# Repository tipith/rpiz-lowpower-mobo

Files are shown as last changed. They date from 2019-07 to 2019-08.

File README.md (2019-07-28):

# Motherboard

Purpose of this PCB is have a low-power way of sending SMS messages once an external trigger is detected. For example, it can be used as a an detector for door open events.

Features
- 18650 battery holder
- Attiny1604 power manager
- External trigger connector
- Nokia phone connector (FBUS + battery size indicator + battery temp)
- 2-way communication between PM and RPi

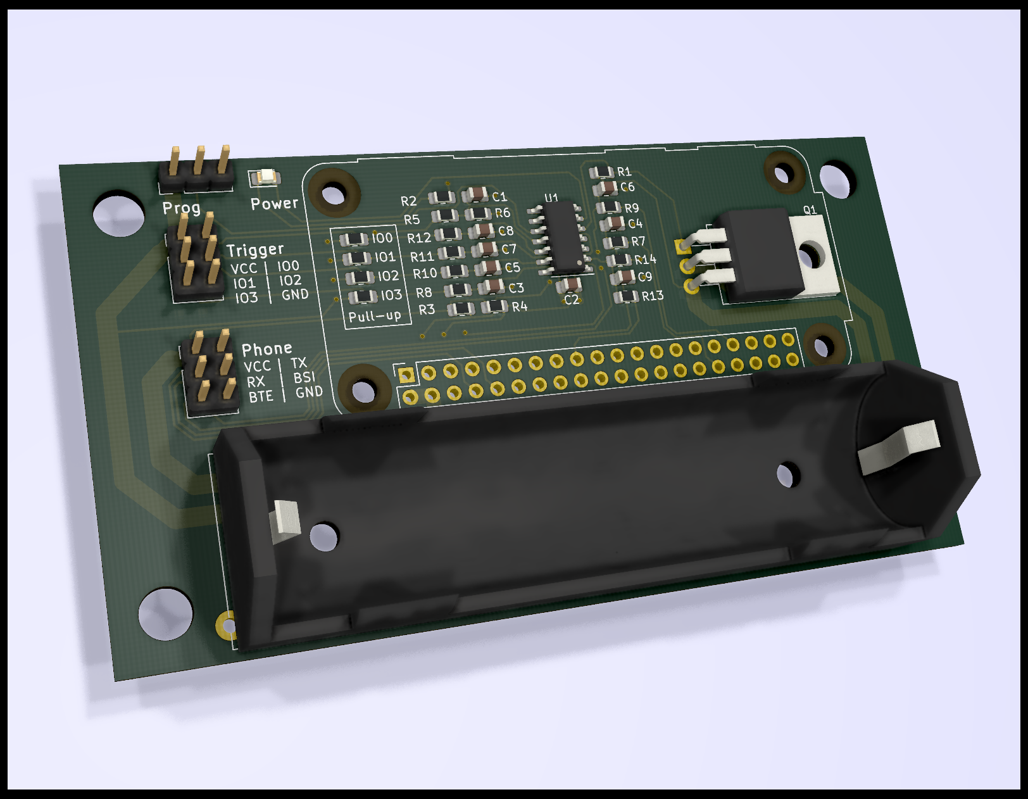
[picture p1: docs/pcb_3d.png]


# Power manager (attiny1604)

tbd

# SMS sender (RPi Zero)

## Instructions

- /boot
   - add file: sshe
   - add file: wpa_supplicant.conf
   - add file: trapsms.ini
- /boot/config.txt
   - add "dtoverlay rpi3-disable-bt"
   - uncomment and modify "dtparam=i2c_arm=on,i2c_arm_baudrate=50000"
-  /boot/cmdline.txt
   - remove "console=serial0,115200 console=tty1"
- shell commands
   - sudo systemctl disable hciuart
   - sudo apt update && sudo apt upgrade
   - sudo apt install git gammu python3-gammu
- install pigpio
  - sudo apt-get install pigpio
  - wget https://raw.githubusercontent.com/joan2937/pigpio/master/util/pigpiod.service
  - sudo cp pigpiod.service /etc/systemd/system
  - sudo systemctl enable pigpiod.service
  - sudo systemctl start pigpiod.service
- run
   - python3 rpi_smssender/sms_sender.py

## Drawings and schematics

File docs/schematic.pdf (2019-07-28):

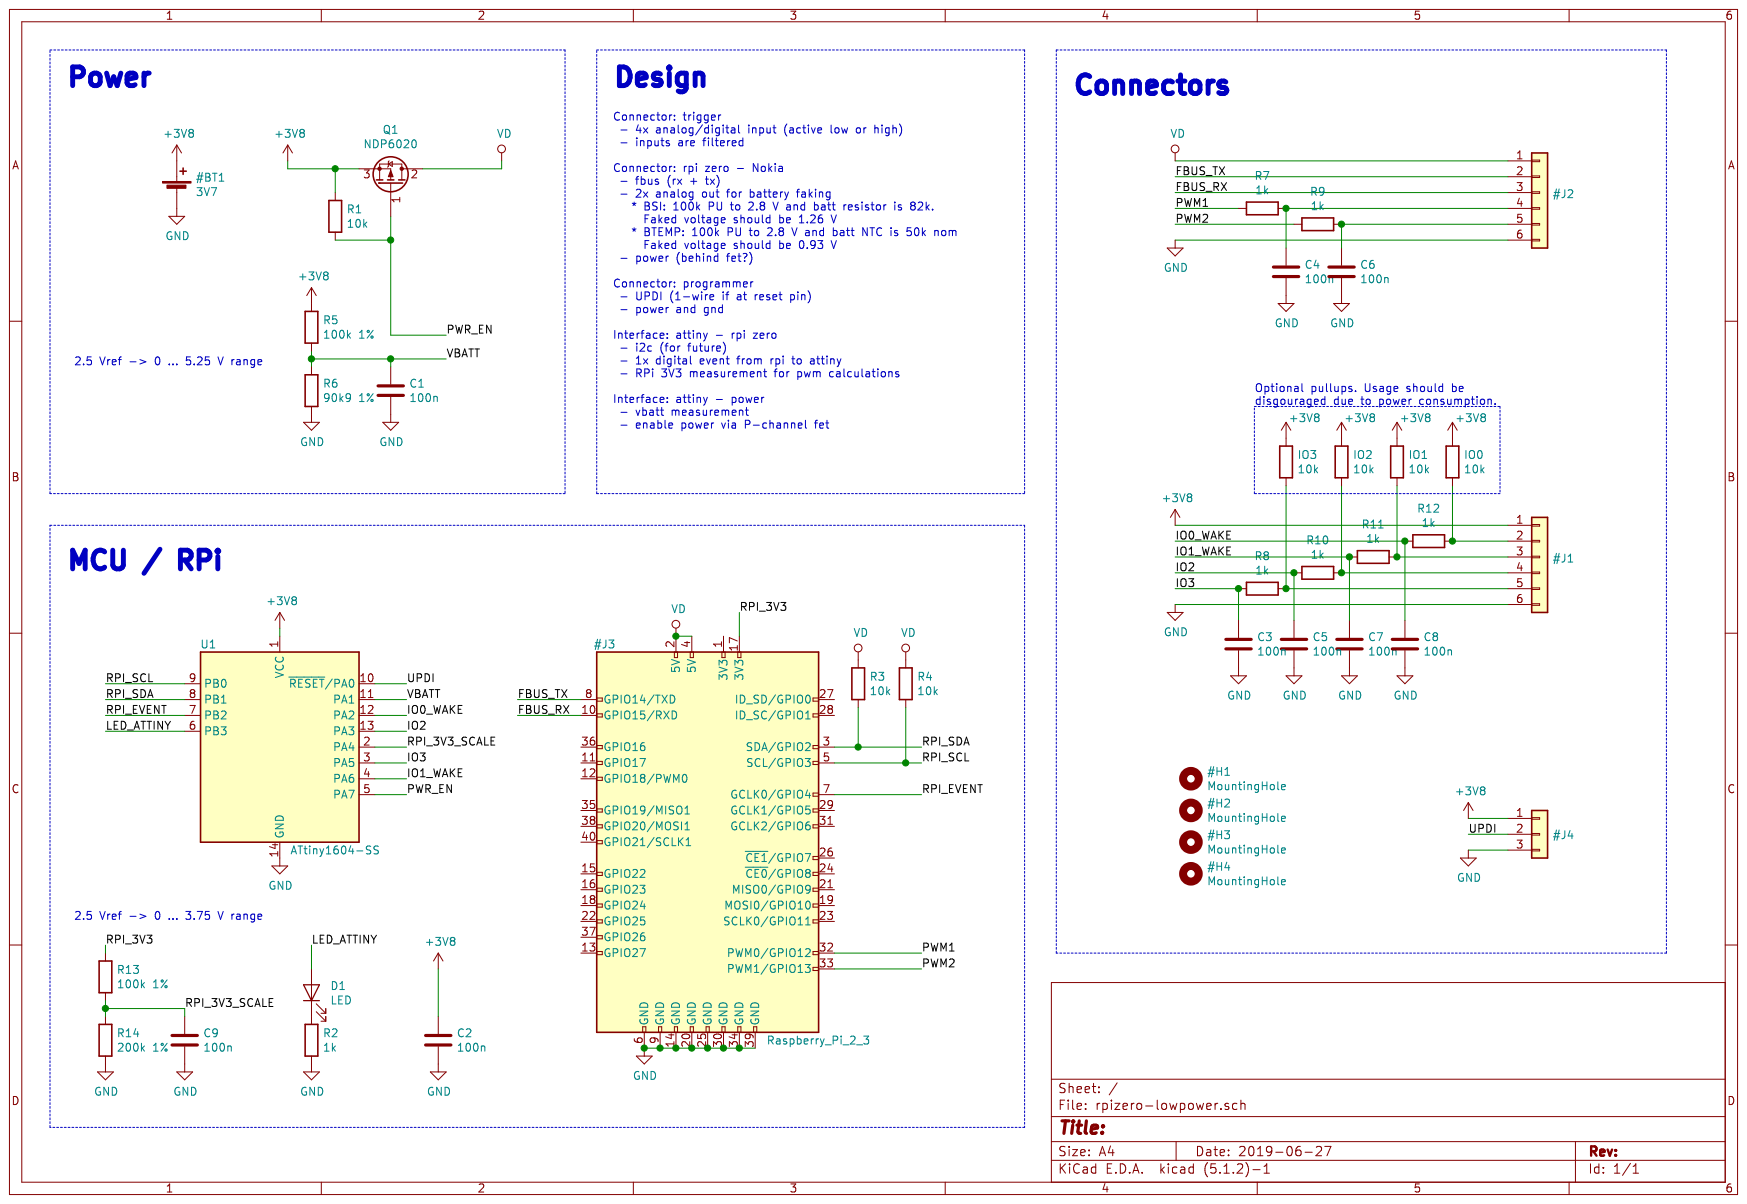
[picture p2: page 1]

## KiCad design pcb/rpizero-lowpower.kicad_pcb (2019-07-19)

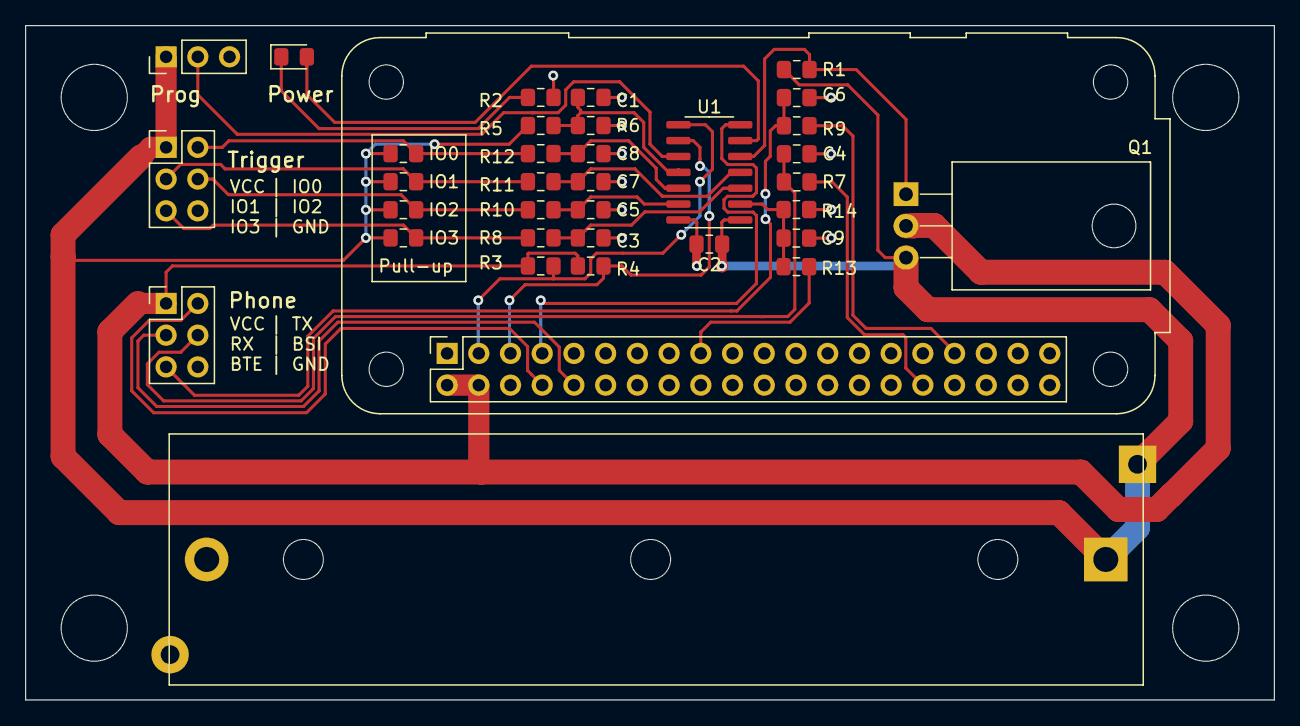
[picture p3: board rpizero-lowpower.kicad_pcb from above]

Board: 2 copper layers, 100.0 x 54.0 mm, 39 parts (0 on the bottom side), 27 nets.

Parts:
BT1: 3V7; 18650-ebay
C1, C2, C4, C6, C9: 100n; C_0805_2012Metric_Pad1.15x1.40mm_HandSolder
C3, C5, C7, C8: 1u; C_0805_2012Metric_Pad1.15x1.40mm_HandSolder
D1: LED; LED_0805_2012Metric_Pad1.15x1.40mm_HandSolder
H1, H2, H3, H4: MountingHole; MountingHole_5.3mm__no_courtyard
IO0, IO1, IO2, IO3: 10k; R_0805_2012Metric_Pad1.15x1.40mm_HandSolder
J1: Screw_Terminal_01x06; PinHeader_2x03_P2.54mm_Vertical
J2: Screw_Terminal_01x04; PinHeader_2x03_P2.54mm_Vertical
J3: Raspberry_Pi_2_3; Raspberry_Pi_Zero_Socketed_THT_FaceDown_MountingHoles_no_co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
J4: Conn_01x03; PinHeader_1x03_P2.54mm_Vertical
Q1: NDP6020; TO-220-3_Horizontal_TabDown
R1: 10k; R_0805_2012Metric_Pad1.15x1.40mm_HandSolder
R2, R7, R8, R9, R10, R11, R12: 1k; R_0805_2012Metric_Pad1.15x1.40mm_HandSolder
R3, R4: 4k7; R_0805_2012Metric_Pad1.15x1.40mm_HandSolder
R5, R13: 100k 1%; R_0805_2012Metric_Pad1.15x1.40mm_HandSolder
R6: 90k9 1%; R_0805_2012Metric_Pad1.15x1.40mm_HandSolder
R14: 200k 1%; R_0805_2012Metric_Pad1.15x1.40mm_HandSolder
U1: ATtiny1604-SS; SOIC-14_3.9x8.7mm_P1.27mm

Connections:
+3V8: BT1.1, C2.1, IO0.1, IO1.1, IO2.1, IO3.1, J1.1, J4.1, Q1.3, R1.1, R5.1, U1.1
/FBUS_RX: J2.3, J3.10
/FBUS_TX: J2.2, J3.8
/IO0_WAKE: C8.1, R12.2, U1.12
/IO1_WAKE: C7.1, R11.2, U1.4
/IO2: C5.1, R10.2, U1.13
/IO3: C3.1, R8.2, U1.3
/LED_ATTINY: D1.2, U1.6
/PWM1: J3.32, R7.2
/PWM2: J3.33, R9.2
/PWR_EN: Q1.1, R1.2, U1.5
/RPI_3V3: J3.17, R13.1
/RPI_3V3_SCALE: C9.1, R13.2, R14.1, U1.2
/RPI_EVENT: J3.7, U1.7
/RPI_SCL: J3.5, R4.2, U1.9
/RPI_SDA: J3.3, R3.2, U1.8
/UPDI: J4.2, U1.10
/VBATT: C1.1, R5.2, R6.1, U1.11
GND: BT1.2, C1.2, C2.2, C3.2, C4.2, C5.2, C6.2, C7.2, C8.2, C9.2, J1.6, J2.6, J3.6, J3.9, J3.14, J3.20, J3.25, J3.30, J3.34, J3.39, J4.3, R2.2, R6.2, R14.2, U1.14
unnamed: C4.1, J2.4, R7.1
unnamed: C6.1, J2.5, R9.1
unnamed: D1.1, R2.1
unnamed: IO0.2, J1.2, R12.1
unnamed: IO1.2, J1.3, R11.1
unnamed: IO2.2, J1.4, R10.1
unnamed: IO3.2, J1.5, R8.1
VD: J2.1, J3.2, J3.4, Q1.2, R3.1, R4.1

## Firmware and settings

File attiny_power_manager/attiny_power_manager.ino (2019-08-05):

#include <Wire.h>
#include <avr/sleep.h>
#include "src/DebugLogger.h"
#include "src/PowerManager.h"
#include "src/debug.h"
#include "src/pmtypes.h"
#include "src/utils.h"

#define I2C_BUFFER_SIZE 32
#define I2C_PAYLOAD_SIZE (I2C_BUFFER_SIZE - 2)  // 2 bytes crc

extern volatile uint32_t timer_millis;

static uint8_t out_data[I2C_BUFFER_SIZE];
static unsigned int out_len = 8;
static PowerManager* pm;
static DebugLogger* dbg;

static void requestEvent()
{
    if (out_len)
        Wire.write(out_data, out_len);
}

static void receiveEvent(int howMany)
{
    int reg = Wire.read();
    out_len = 0;

    switch (reg)
    {
        case REG_VBATT:
            out_len += pack_u16(out_data, pm->vbatt());
            break;
        case REG_VRPI:
            out_len += pack_u16(out_data, pm->vrpi());
            break;
        case REG_STARTUP_REASON:
            out_len += pack_u16(out_data, pm->get_reason());
            break;
        case REG_TEMPERATURE:
            out_len += pack_u16(out_data, pm->temperature());
            break;
        case REG_DEBUG_DATA_READ:
            memset(out_data, 0, sizeof(out_data));
            dbg->read(out_data, I2C_PAYLOAD_SIZE);
            out_len = I2C_PAYLOAD_SIZE;
            break;
        case REG_REQUEST_SHUTDOWN:
            if (Wire.available() == 4)
            {
                uint16_t secs = Wire.read() | (Wire.read() << 8);
                uint16_t crc = Wire.read() | (Wire.read() << 8);
                if (calculate_crc16((uint8_t*)&secs, 2) == crc)
                    pm->request_shutdown(secs);
            }
            break;
    }

    if (out_len)
        out_len = append_crc16(out_data, out_len);
}

static void event_ext0(void)
{
    pm->ext(IPowerState::EXT_SOURCE_1);
}

static void event_ext1(void)
{
    pm->ext(IPowerState::EXT_SOURCE_2);
}

static void sleep_if_needed(void)
{
    cli();
    if (pm->is_powered() == false)
    {
        DBG_PRINTF("s");
        sei();
        sleep_mode();
        cli();
        timer_millis += 1000;
        sei();
        DBG_PRINTF("w");
    }
    else
    {
        sei();
        delay(1000);
    }
}

void RTC_init(void)
{
    while (RTC.STATUS > 0)
        ;
    RTC.CLKSEL = RTC_CLKSEL_INT32K_gc;                    /* 32.768kHz Internal Crystal */
    RTC.PITINTCTRL = RTC_PI_bm;                           /* PIT Interrupt: enabled */
    RTC.PITCTRLA = RTC_PERIOD_CYC32768_gc | RTC_PITEN_bm; /* 1 Hz */
}

ISR(RTC_PIT_vect)
{
    RTC.PITINTFLAGS = RTC_PI_bm; /* Clear interrupt flag */
}

void setup()
{
    pinMode(PIN_PWR_EN, OUTPUT);
    pinMode(PIN_LED, OUTPUT);
    // indication to rpi if attiny is sleeping, should preent i2c polling
    pinMode(PIN_RPI_EVENT, OUTPUT);

    dbg = new DebugLogger(256);
    debug_set_logger(dbg);
    pm = new PowerManager();

    // TWI will be enabled on power on to reduce current consumption
    Wire.onRequest(requestEvent);
    Wire.onReceive(receiveEvent);

    attachInterrupt(digitalPinToInterrupt(PIN_IO0), event_ext0, FALLING);
    attachInterrupt(digitalPinToInterrupt(PIN_IO1), event_ext1, FALLING);

    set_sleep_mode(SLEEP_MODE_PWR_DOWN);
    sleep_enable();

    RTC_init();
}

void loop()
{
    pm->timer();
    sleep_if_needed();
}

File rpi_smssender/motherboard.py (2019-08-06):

import time
import struct
import sys
import pigpio
import crcmod
import logging
from enum import IntEnum
from typing import *
from threading import Thread, RLock
from pins import *


logger = logging.getLogger('mobo')

class StartupReason(IntEnum):
    EXT_TRIGGER1 = 1
    EXT_TRIGGER2 = 2
    LOW_BATTERY = 3
    UNKNOWN = 4

    @classmethod
    def has_value(cls, value):
        return any(value == item.value for item in cls)


class I2CRegister(IntEnum):
    REG_VBATT = 1
    REG_RPI_3V3 = 2
    REG_STARTUP_REASON = 3
    REG_TEMPERATURE_KELVIN = 4
    REG_DEBUG_DATA_READ = 5
    REG_REQUEST_SHUTDOWN = 6

class SleepingException(Exception):
    pass

class CommunicationError(Exception):
    pass

class Motherboard(Thread):

    def __init__(self, addr=8):
        super().__init__()
        self.pi = pigpio.pi()
        self.i2c = self.pi.i2c_open(1, addr)
        self.ops = {'total': 0, 'fail': 0}
        self.i2c_lock = RLock()
        self.running = True
        self.remains = ''
        self.pi.set_mode(PIN_SLEEP_STATUS, pigpio.INPUT)

    def run(self):
        while self.running:
            try:
                dbg_lines = self.debug
                for line in dbg_lines:
                    logger.info(line)
            except SleepingException:
                pass
            except CommunicationError as e:
                logger.warn(e)
            time.sleep(0.01)

    def stop(self):
        self.running = False
        self.join(1)
        self.pi.i2c_close(self.i2c)
        self.pi.stop()

    def _read_reg_word(self, reg: I2CRegister):
        for _ in range(4):
            try:
                payload = self._read_buffer(reg, 2)
                return struct.unpack('<H', payload)[0]
            except CommunicationError as e:
                logger.warn(f'error: {e}, ops: {self.ops}')
                time.sleep(1)
            except SleepingException:
                break

    def _write_buffer(self, reg: I2CRegister, data):
        if self.sleeping:
            raise SleepingException(f'power manager is sleeping')
        with self.i2c_lock:
            crc_func = crcmod.predefined.mkCrcFun('xmodem')
            data += struct.pack('<H', crc_func(data))
            logger.debug(f'{str(reg):<20}: {data}')
            self.pi.i2c_write_i2c_block_data(self.i2c, reg, data)

    def _read_buffer(self, reg: I2CRegister, count):
        if self.sleeping:
            raise SleepingException(f'power manager is sleeping')
        with self.i2c_lock:
            self.ops['total'] += 1
            (s, b) = self.pi.i2c_read_i2c_block_data(self.i2c, reg, count + 2)
        if s >= 0:
            payload = b[:count] 
            crc = b[count:]
            expected_crc = struct.unpack('<H', crc)[0]
            crc_func = crcmod.predefined.mkCrcFun('xmodem')
            calculated_crc = crc_func(payload)
            if expected_crc != calculated_crc:
                self.ops['fail'] += 1
                raise CommunicationError(f'crc mismatch, reg {reg}, expected {hex(expected_crc)} != calculated {hex(calculated_crc)}\n - data: {b}')
            logger.debug(f'{str(reg):<20}: {payload}')
            return payload
        else:
            self.ops['fail'] += 1
            raise CommunicationError(f'unable to communicate, reg {reg}, status {s}')

    @property
    def sleeping(self):
        return self.pi.read(PIN_SLEEP_STATUS) == 1

    @property
    def v_rpi_3v3(self):
        val = self._read_reg_word(I2CRegister.REG_RPI_3V3)
        return val / 1e3 if val is not None else None

    @property
    def v_batt(self):
        val = self._read_reg_word(I2CRegister.REG_VBATT)
        return val / 1e3 if val is not None else None

    @property
    def temperature(self):
        val = self._read_reg_word(I2CRegister.REG_TEMPERATURE_KELVIN)
        return val - 273 if val is not None else None

    @property
    def startup_reason(self) -> StartupReason:
        val = self._read_reg_word(I2CRegister.REG_STARTUP_REASON)
        return StartupReason(val) if StartupReason.has_value(val) else StartupReason.UNKNOWN

    @property
    def debug(self) -> List[str]:
        MAX_DBG_PAYLOAD = 30
        ret = ''
        while True:
            buf = self._read_buffer(I2CRegister.REG_DEBUG_DATA_READ, MAX_DBG_PAYLOAD)
            if buf is not None and len(buf) > 0:
                ret += buf.decode('ascii', errors='ignore')
            if all(map(bool, ret)) and len(ret) < 128:  # retry if payload is filled
                time.sleep(0.01)
                continue
            break
        previous = self.remains
        *full_rows, self.remains = ret.split('\n')
        if len(full_rows):
            full_rows[0] = previous + full_rows[0]  # prepend the found line with previous
        else:
            self.remains = previous + self.remains  # one long line still continues
        return full_rows
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

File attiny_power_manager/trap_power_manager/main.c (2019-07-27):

/*
 * trap_power_manager.c
 *
 * Created: 30/06/2019 19.12.51
 * Author : pihlstro
 */ 
#include <avr/io.h>
#include <avr/sleep.h>
#include <avr/interrupt.h>

#include "adc.h"
#include "gpio.h"
#include "timer.h"
#include "statemachine.h"

enum wake_event {
	EVENT_NONE,
	EVENT_EXT1,
	EVENT_EXT2,
	EVENT_RPI,
	EVENT_TIMER
};

bool timer_occured = false;
bool ext1_occured = false;
bool ext2_occured = false;
bool rpi_occured = false;

static void _sleepy(void)
{
	set_sleep_mode(SLEEP_MODE_PWR_DOWN);
	sleep_mode();
}

static void _on_ext_trigger1(void)
{
	ext1_occured = true;
	cli();
}

static void _on_ext_trigger2(void)
{
	ext2_occured = true;
	cli();
}

static void _on_rpi_event(void)
{
	rpi_occured = true;
}

static void _on_timer(void)
{
	timer_occured = true;
}

enum wake_event inspect_and_clear_event_source(void)
{
	if (ext1_occured)
	{
		ext1_occured = false;
		return EVENT_EXT1;
	}
	
	if (ext2_occured)
	{
		ext2_occured = false;
		return EVENT_EXT2;
	}
	
	if (rpi_occured)
	{
		rpi_occured = false;
		return EVENT_RPI;
	}

	if (timer_occured)
	{
		timer_occured = false;
		return EVENT_TIMER;
	}

	return EVENT_NONE;
}

void _sleep(uint32_t n)
{
	for(uint32_t t1 = 0; t1 < n; ++t1)
	{
		for(uint32_t t2 = 0; t2 < 80000; ++t2);
	}
}

void blink(uint32_t n)
{
	for(uint32_t t1 = 0; t1 < n; ++t1)
	{
		gpio_set(PIN_LED);
		for(uint32_t t2 = 0; t2 < 40000; ++t2);
		gpio_clear(PIN_LED);
		for(uint32_t t3 =0; t3 < 40000; ++t3);
	}
}

int main(void)
{
	gpio_init();
	gpio_subscribe(PIN_IO0, _on_ext_trigger1);
	gpio_subscribe(PIN_IO1, _on_ext_trigger2);
	gpio_subscribe(PIN_RPI_EVENT, _on_rpi_event);

	
	adc_init();
	
	timer_init();
	timer_schedule_periodical(60, _on_timer);
	
	statemachine_init();

	_sleep(3);
	blink(1);

    while (1) 
    {
		sei();
		//_sleepy();
		
		switch (inspect_and_clear_event_source())
		{
			case EVENT_EXT1:
				statemachine_ext_event(EXT_SOURCE_1);
				//blink(1);
				break;
			case EVENT_EXT2:
				statemachine_ext_event(EXT_SOURCE_2);
				//blink(2);
				break;
			case EVENT_RPI:
				statemachine_rpi_event();
				blink(3);
				break;
			case EVENT_TIMER:
				statemachine_timer_event();
				blink(4);
				break;
			default:
				break;
		}

		_sleep(3);
    }
}

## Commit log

2019-07-19 bom updated with mouser part numbers
    [rpizero-lowpower.sch]
2019-07-27 add power manager and refactor into directories
    [rpizero-lowpower-B_Cu.gbl, rpizero-lowpower-B_Mask.gbs, rpizero-lowpower-B_SilkS.gbo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]
2019-07-28 add i2c communication between attiny and rpi zero
2019-07-30 add temperature register
2019-08-03 logging via i2c
